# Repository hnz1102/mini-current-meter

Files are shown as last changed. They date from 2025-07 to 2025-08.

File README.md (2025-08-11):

<div align="center">
  <h1><code>Mini Current Meter</code></h1>
  <p>
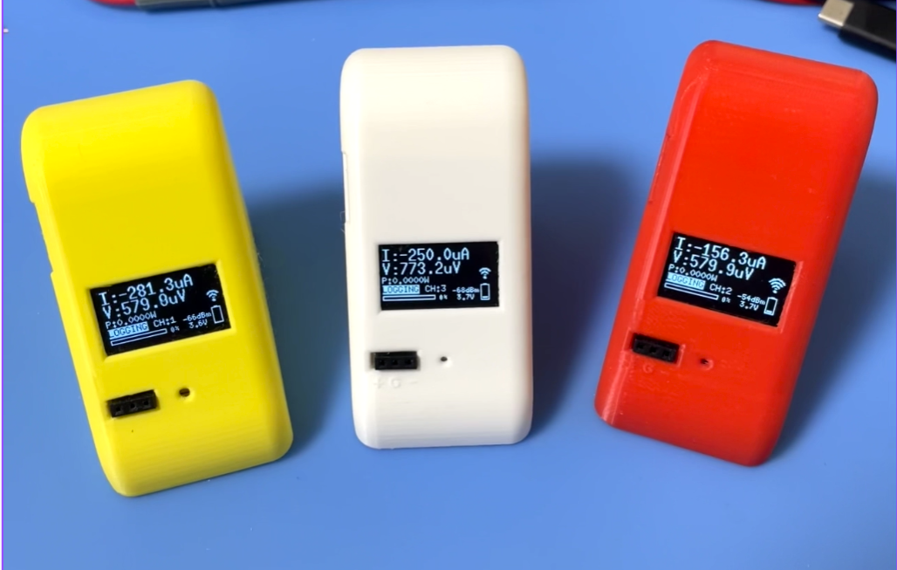
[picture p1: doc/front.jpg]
    
  </p>
</div>

# Mini Current Meter - Mini Size High-resolution Digital Power Monitor and Logger

This tool provides a logging function that captures data on voltage, current and power consumption. Voltage input range is from 0 to 35V, maximum current input is 10A. 

# Features

**High-resolution** - By using Texas Instruments INA228 IC - 20-bit delta-sigma ADC, it can obtain measurement data with 195µV bus voltage and 163.84mV shunt voltage resolution.

**Microcontroller on board** - No need for a client PC when measuring. Data is sent directly to the server.

**Transfer measurement data via WiFi** - This logger can transfer data to a Linux PC via WiFi network and you can view the dashboard graph in InfluxDB.

**Calibration Function** - Built-in calibration functionality with persistent storage. Long press the center button for 2+ seconds to perform automatic calibration that corrects voltage and current measurement offsets. Calibration results are automatically saved to non-volatile storage and restored on power-up.

**Change Channel** - This logger allows you to change the measurement channel by pushing the center button with a pin. Once you push the center button, the channel will change to the next channel. The channel cycles through 1, 2, 3, 4, and back to 1.

**Battery Powered** - Uses LiPo battery. It can run for 12 hours on a single charge. The battery is charged via USB Type-C port.

**Mini Size** - The dimensions are 37mm(W) x 67mm(D) x 55mm(H). It can be used in various locations.

# How to Use the Logger

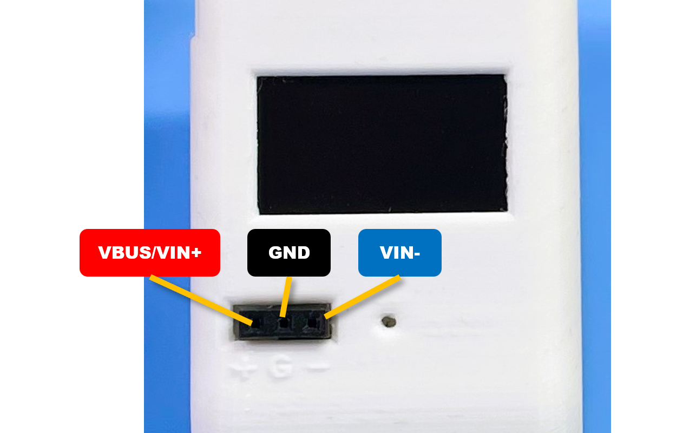
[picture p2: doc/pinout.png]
PinOut


This meter has a pin socket with three pins: VBUS/VIN+, GND, and VIN-. The VBUS/VIN+ pin is connected to the voltage input or the current input. The GND pin is connected to the ground of the voltage or current input. The VIN- pin is connected to the load side of the voltage or current input.

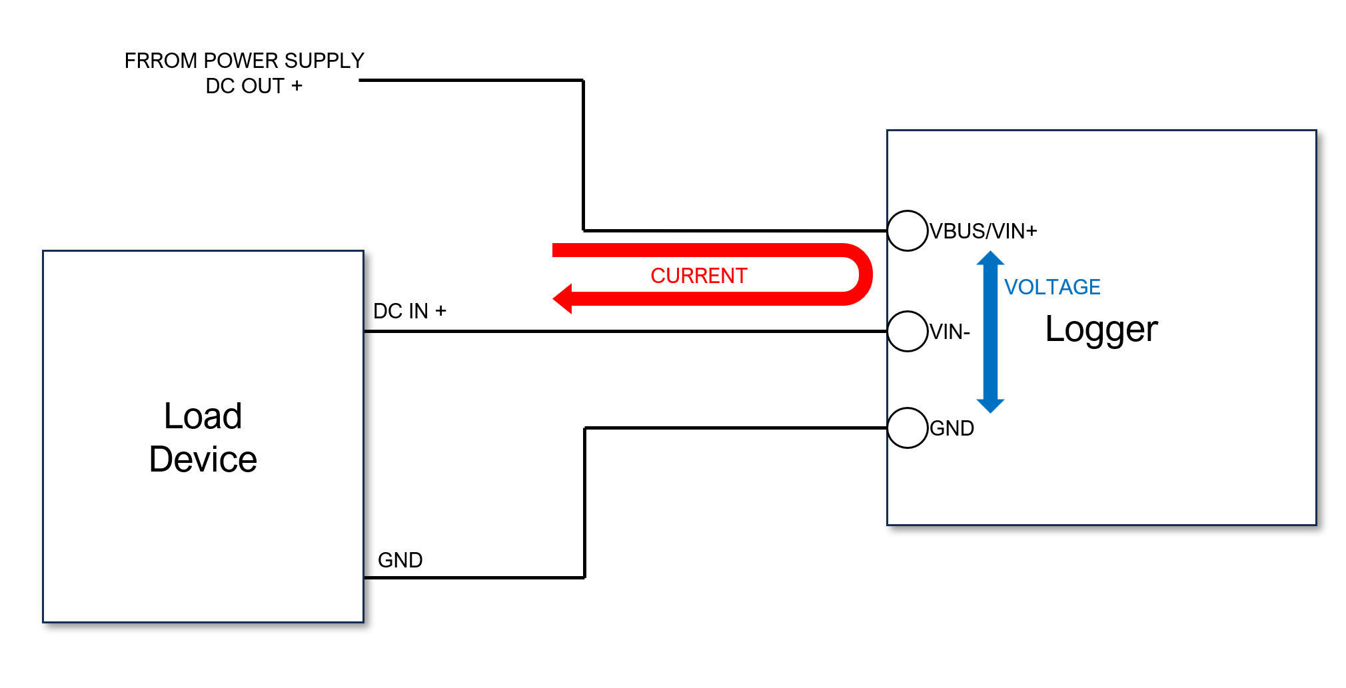
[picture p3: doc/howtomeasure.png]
How to connect


DO NOT CONNECT WITH REVERSE POLARITY BETWEEN VBUS/VIN+ AND GND. IF CONNECTED INCORRECTLY, THE ADC IC WILL BE DAMAGED.

The measurement interval time is fixed at 100ms. Each measurement data is sent to the server every 1 second.

The display shows the current voltage, current, power consumption, battery voltage, buffer consumption, WiFi connection status, and channel number.
If the WiFi Access Point cannot establish a connection, the display will not show the WiFi indicator. If voltage is measured while WiFi is not connected, the data is stored in the logger's internal memory buffer. The buffer that is not being sent to the server is indicated by a buffer bar on the display. When the buffer is full (the bar reaches the right edge of the display), measurement stops automatically. When WiFi is connected and data is transmitted to the server, the buffer bar shrinks to the left. When the buffer is full and measurement is stopped, measurement will resume automatically after the buffer drops below 50%.

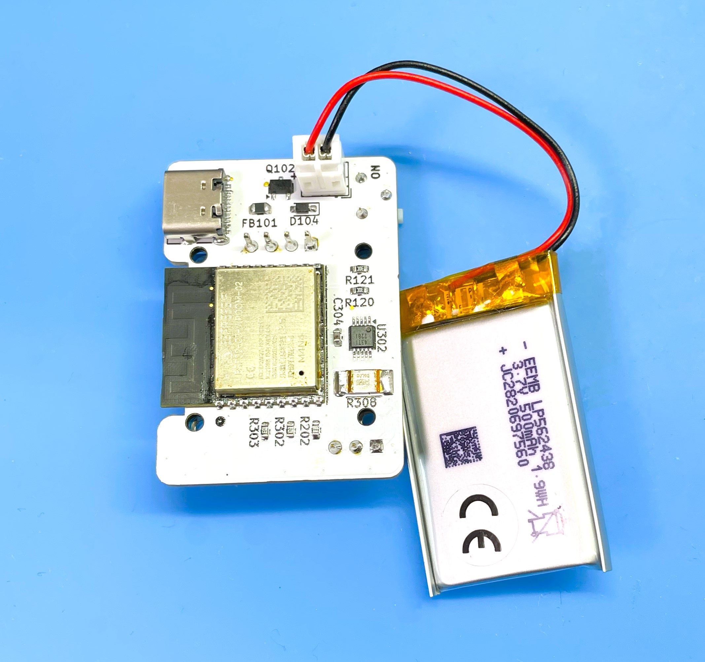
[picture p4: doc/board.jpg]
board


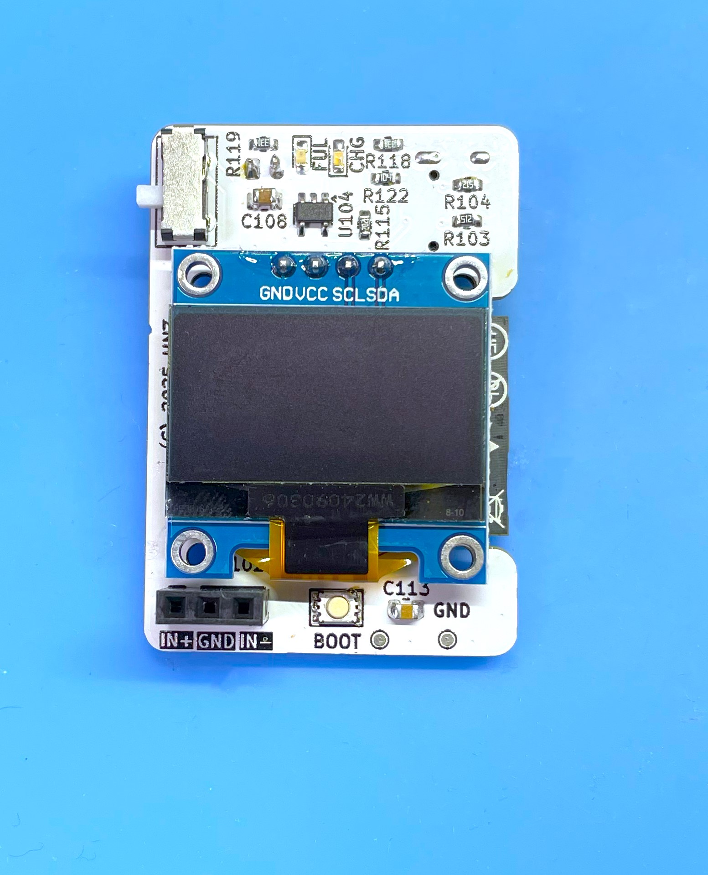
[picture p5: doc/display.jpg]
Display


If you send data to the server, you can see real-time data using the Dashboard in [InfluxDB](https://www.influxdata.com/influxdb/). If you have 3 meters, you can view data on the dashboard with different channels simultaneously.

These meters are small and light, so you can use them in various locations. For example, you can use them to measure circuit current on your breadboard, or you can measure the current at each measurement point on your breadboard circuit. 

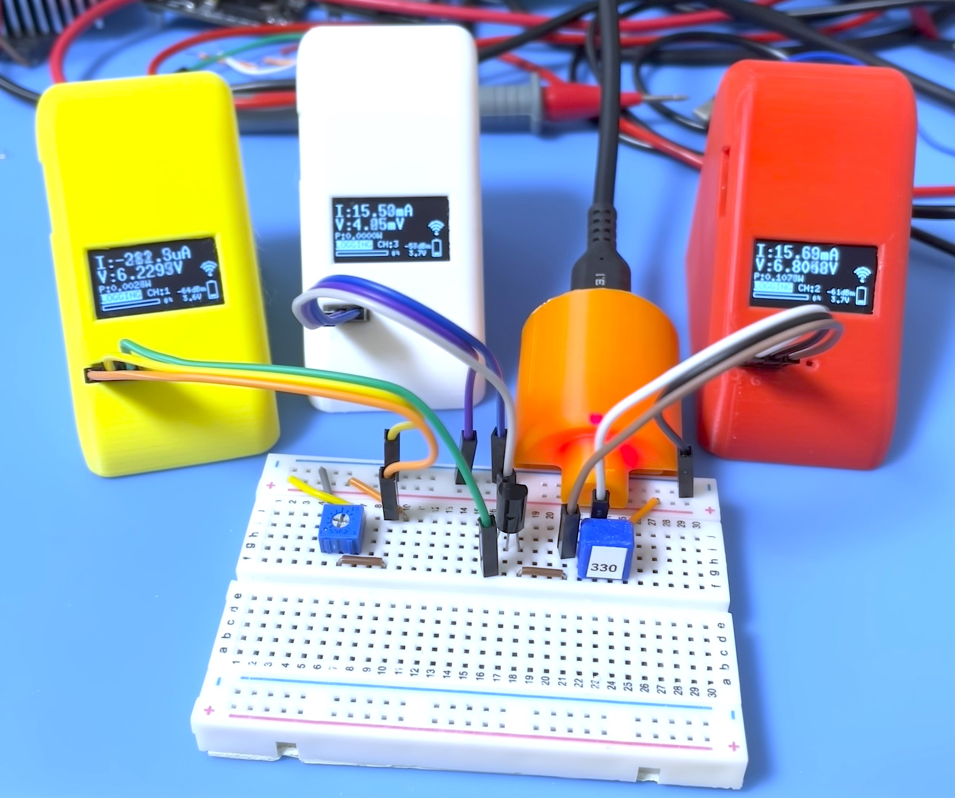
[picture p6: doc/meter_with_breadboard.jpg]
breadboard


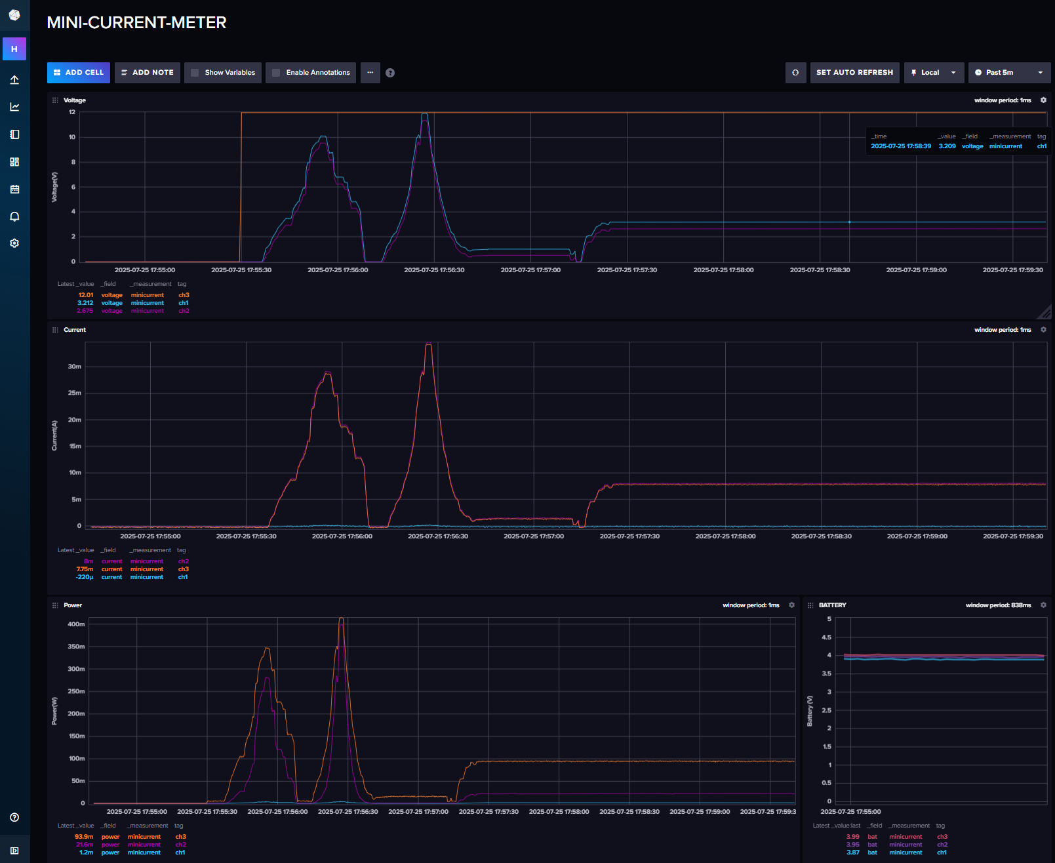
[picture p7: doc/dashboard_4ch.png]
dashboard


To charge the battery, simply connect to a USB Type-C port from a bus-powered USB port. During charging, the CHG LED is RED. After charging is complete, the FUL LED is GREEN and charging will stop automatically. However,

DO NOT CONTINUE CHARGING IF THE BATTERY IS FULL FOR A LONG TIME.

# Calibration Function

The Mini Current Meter includes built-in calibration functionality to correct measurement offsets and improve accuracy.

## How to Perform Calibration

1. **Prepare for calibration**: Ensure no current is flowing through the shunt resistor and no voltage is applied to the measurement inputs (VBUS/VIN+ and GND should be at the same potential).

2. **Start calibration**: Press and hold the center button for **2-5 seconds**. The display will show "Calibrating..." message.

3. **Calibration process**: The device automatically takes 300 samples over 3 seconds to calculate average voltage and current offsets.

4. **Completion**: When calibration is complete, the display will show "Calibration OK" for 2 seconds, and the offset values will be automatically saved to non-volatile storage.

## Button Functions

- **Short press** (< 2 seconds): Change measurement channel (1-4)
- **Long press** (2+ seconds): Perform calibration

## Calibration Features

- **Automatic offset correction**: Calibration corrects both voltage and current measurement offsets
- **Persistent storage**: Calibration results are automatically saved to NVS (Non-Volatile Storage) and restored on power-up
- **High accuracy**: Uses 300-sample averaging for precise offset calculation
- **User feedback**: Real-time status display during calibration process

## When to Calibrate

- **Initial setup**: Perform calibration when first using the device
- **Temperature changes**: Recalibrate if operating temperature changes significantly
- **Accuracy concerns**: If measurements appear to have a systematic offset
- **After firmware updates**: Recalibration recommended after major firmware changes

**Note**: Always ensure zero current flow and zero voltage difference during calibration for best results.

# Recent Updates

## Version 2025.08 - Calibration and Accuracy Improvements

- **Added calibration functionality**: Built-in calibration system with persistent storage
- **Improved measurement accuracy**: Automatic offset correction for voltage and current readings
- **Enhanced button handling**: Added debouncing and multi-function button support (channel change, calibration, reset)
- **NVS integration**: Calibration data automatically saved and restored across power cycles
- **User interface improvements**: Real-time calibration status display and user feedback
- **Error correction**: Fixed voltage measurement accuracy issues and ADC offset handling

# How to Build from Code and Install to the Unit

Using Ubuntu 22.04 LTS

1. Install Rust Compiler
```bash
sudo apt update && sudo apt -y install git python3 python3-pip gcc build-essential curl pkg-config libudev-dev libtinfo5 clang libclang-dev llvm-dev udev libssl-dev python3.10-venv
curl --proto '=https' --tlsv1.2 -sSf https://sh.rustup.rs | sh
```

select No.1

After installation, you need to set the environment variable for Rust.
Add the following line to your shell configuration file (e.g., `~/.bashrc`, `~/.zshrc`, etc.):
```bash
source "$HOME/.cargo/env"
```

2. Install toolchain for ESP32-C3
```bash
cargo install ldproxy
cargo install espup
cargo install cargo-espflash
```

At this time (2025-07-25), espup cannot be compiled. If you get an error, please use the following command to install the toolchain.
```bash
cargo install cargo-binstall
cargo binstall espup
```

```bash
espup install
espup update
```

Then, run the following command to set the environment for the ESP32-C3 toolchain:
```bash
. ./export-esp.sh
```

3. Add UDEV rules
```bash
sudo sh -c 'echo "SUBSYSTEMS==\"usb\", ATTRS{idVendor}==\"303a\", ATTRS{idProduct}==\"1001\", MODE=\"0666\"" > /etc/udev/rules.d/99-esp32.rules'
sudo udevadm control --reload-rules
sudo udevadm trigger
```

4. Download Mini Current Meter code
```bash
git clone https://github.com/hnz1102/mini-current-meter.git
cd mini-current-meter/code
``` 
5. Setting WiFi SSID, Password, and InfluxDB Server IP Address

You need to set the WiFi SSID, password, and InfluxDB server IP address in the configuration file.
You can find the configuration file 'cfg.toml.samp' in the `code` directory. You need to copy this file to `cfg.toml` and edit it.

```bash
nano code/cfg.toml

[mini-current-meter]
wifi_ssid = "XXXXXXXXXXXX"  # Set your WiFi SSID.
wifi_psk = "XXXXXXXXXXXXX"  # Set your WiFi Password.
shunt_resistance = "0.005"
influxdb_server = "<IP Address>:8086"  # Set your InfluxDB server IP address.
influxdb_api_key = "<API_KEY>" # Set your InfluxDB API Key.
influxdb_api = "/api/v2/write?org=<ORG>&bucket=LOGGER&precision=ns" # Set your InfluxDB API URL. You must set <ORG> same as Initial Organization Name.
influxdb_tag = "ch"
influxdb_measurement = "minicurrent"
max_records = "1023"
```

6. Connecting the Board and Setting Device and Toolchain
```bash
Connect the mini-current-meter via USB to this build code PC. Then, 
$ cargo espflash board-info
select /dev/ttyACM0
Chip type:         esp32c3 (revision v0.4)
Crystal frequency: 40MHz
Flash size:        4MB
Features:          WiFi, BLE
MAC address:       xx:xx:xx:xx:xx:xx

$ rustup component add rust-src --toolchain nightly-2023-06-10-x86_64-unknown-linux-gnu
```

7. Build Code and Write to Flash
```bash
$ cargo espflash flash --release --monitor
App/part. size:    964,240/3,145,728 bytes, 30.23%
[00:00:00] [========================================]      12/12      0x0                                                                       
[00:00:00] [========================================]       1/1       0x8000                                                                    
[00:00:11] [========================================]     546/546     0x10000                                                                   [2023-11-11T10:17:05Z INFO ] Flashing has completed!

Automatically boots!
```
# How to Install InfluxDB

1. Download [InfluxDB](https://docs.influxdata.com/influxdb/v2.7/install/?t=Linux) and Install
```bash
$ wget https://dl.influxdata.com/influxdb/releases/influxdb2-2.7.0-amd64.deb
$ sudo dpkg -i influxdb2-2.7.0-amd64.deb
$ sudo service influxdb start
```

2. Configure InfluxDB

```
Connect to 'http://<InfluxDB installed PC Address>:8086'
```
Click `GET STARTED` and set `Username`, `Password`, `Initial Organization Name`, and `Initial Bucket Name`
|Term|Value|
|---|---|
|Username|Set login username as InfluxDB administrator web console|
|Password|Set login password as InfluxDB administrator web console|
|Initial Organization Name| Organization Name ex. ORG|
|Initial Bucket Name| LOGGER |

After setting these, click `CONTINUE`.

3. Copy the Operator API Token

You can see the operator API token in the browser. YOU WON'T BE ABLE TO SEE IT AGAIN!
If you want to get a new API token, click `API Tokens` menu from `Sources` Icon, then click `GENERATE API TOKEN` and select `All access token`, click `Save`.
You can see the new API token and copy it.
After copying the token, click `CONFIGURE LATER`.

4. Import the Dashboard Template

Click the `Dashboard` icon, and select `Import Dashboard` from the `CREATE DASHBOARD` menu.

Drop the `mini-current-meter/dashboard/mini-current-meter.json` file to `Drop a file here`, then click `IMPORT JSON AS DASHBOARD`.

You can see the `Mini Current Meter Dashboard` panel on the Dashboards page.

Click this panel, and you can see the Mini Current Meter Dashboard.

If you want to customize the dashboard design, click the configure mark. You can change the graph design.

6. Start Mini Current Meter Logging and Send Data

Turn on the power switch. Logging data will be sent to InfluxDB. You can see the data on the dashboard.

## Schematic, PCB Gerber and Container 3D Data

There is schematic data in the hardware directory including 3D printing data as 3MF format files. 

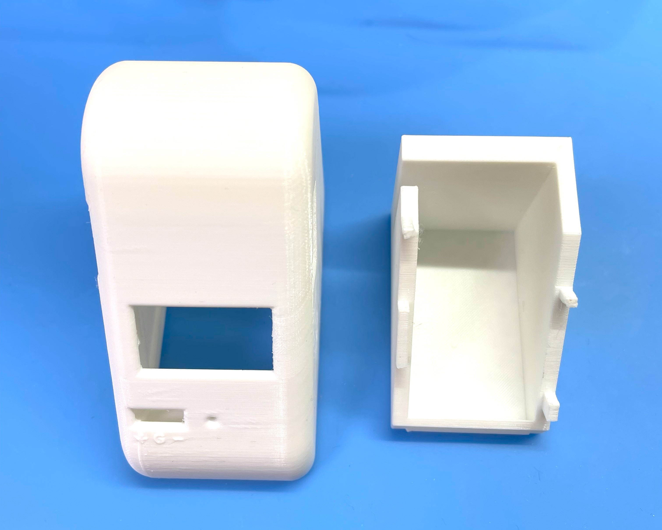
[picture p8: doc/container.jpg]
Container


## LICENSE
This source code is licensed under MIT. Other Hardware Schematic documents are licensed under CC-BY-SA V4.0.

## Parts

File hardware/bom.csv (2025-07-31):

Reference | Value | Footprint | Qty | digikey | DNP
C108 | 4.7uF | Capacitor_SMD:C_0805_2012Metric | 1 | 1276-1244-1-ND
C109,C113 | 1uF | Capacitor_SMD:C_0805_2012Metric | 2 | 1276-1029-1-ND
C111,C304 | 0.1uF | Capacitor_SMD:C_0603_1608Metric | 2 | 311-1088-1-ND
C112 | 10uF | Capacitor_SMD:C_0805_2012Metric | 1 | 587-1300-1-ND
D102 | LED RED | LED_SMD:LED_0603_1608Metric_Pad1.05x0.95mm_HandSolder | 1 | 3147-B1931URO-20D000114U1930CT-ND
D103 | LED GREEN | LED_SMD:LED_0603_1608Metric_Pad1.05x0.95mm_HandSolder | 1 | 3147-B1911PG--20D000514U1930CT-ND
D104 | CUS10F30 | Diode_SMD:D_SOD-323_HandSoldering | 1 | CUS10F30H3FCT-ND
FB101 | MH2029-601Y | Inductor_SMD:L_0805_2012Metric | 1 | MH2029-601YCT-ND
J101 | USB4105-GF-A | Lib:USB_C_5077CR-16-SMC2-BK-TR | 1 | 2073-USB4105-GF-ACT-ND
J102 | Conn_01x03 | Connector_PinSocket_2.54mm:PinSocket_1x03_P2.54mm_Vertical | 1 | https://akizukidenshi.com/catalog/g/g110098/
J103 | LiPo BATTERY | Connector_JST:JST_PH_B2B-PH-K_1x02_P2.00mm_Vertical | 1 | 455-1704-ND, Battey: https://www.amazon.com/EEMB-Battery-Rechargeable-Connector-Certified/dp/B09DPPMX14
Q102 | SSM3J332R | Package_TO_SOT_SMD:SOT-23 | 1 | 4518-SSM3J332RCT-ND
R103,R104 | 5.1K | Resistor_SMD:R_0603_1608Metric | 2 | 311-5.10KHRCT-ND
R106,R120,R121 | 20K 1% | Resistor_SMD:R_0603_1608Metric | 3 | 311-20.0KHRCT-ND
R107 | 12K 1% | Resistor_SMD:R_0603_1608Metric | 1 | 311-12.0KHRCT-ND
R108,R110,R202,R302,R303,R304 | 10K | Resistor_SMD:R_0603_1608Metric | 6 | 311-10KGRCT-ND
R115 | 2K | Resistor_SMD:R_0603_1608Metric | 1 | 311-2.0KGRCT-ND
R118,R119 | 330 | Resistor_SMD:R_0603_1608Metric | 2 | 311-330GRCT-ND
R122 | 100K | Resistor_SMD:R_0603_1608Metric | 1 | RMCF0603FT100KCT-ND
R308 | 5m | Resistor_SMD:R_2512_6332Metric_Pad1.40x3.35mm_HandSolder | 1 | 4506-PEWF2512D5L00Q9CT-ND
SW105 | SLIDE_SW | Lib:SLIDE_SW_IS1235-G | 1 | SLIDE_SW_IS1235-G https://akizukidenshi.com/catalog/g/g115368/
SW201 | 3.5x2.6 Tact SW | Lib:WS-TASV SMT Tact Switch | 1 | 732-435151014824CT-ND
TP101 | GND | TestPoint:TestPoint_Pad_D1.0mm | 1 | -
TP202 | BOOT | TestPoint:TestPoint_Pad_D1.0mm | 1 | -
U101 | ESP32-C3-WROOM-02-N4 | Lib:IC18_ESP32-C3-WROOM-02-N4_EXP | 1 | 1965-ESP32-C3-WROOM-02-N4CT-ND
U102 | SPX3819M5-L/TR | Package_TO_SOT_SMD:SOT-23-5 | 1 | 1016-1871-1-ND
U103 | SSD1306_DISPLAY | Lib:OLED I2C DISPLAY | 1 | https://akizukidenshi.com/catalog/g/g112031/
U104 | MCP73831-2-OT | Package_TO_SOT_SMD:SOT-23-5 | 1 | https://akizukidenshi.com/catalog/g/g113288/
U302 | INA228 | Package_SO:VSSOP-10_3x3mm_P0.5mm | 1 | 296-INA228AIDGSRCT-ND

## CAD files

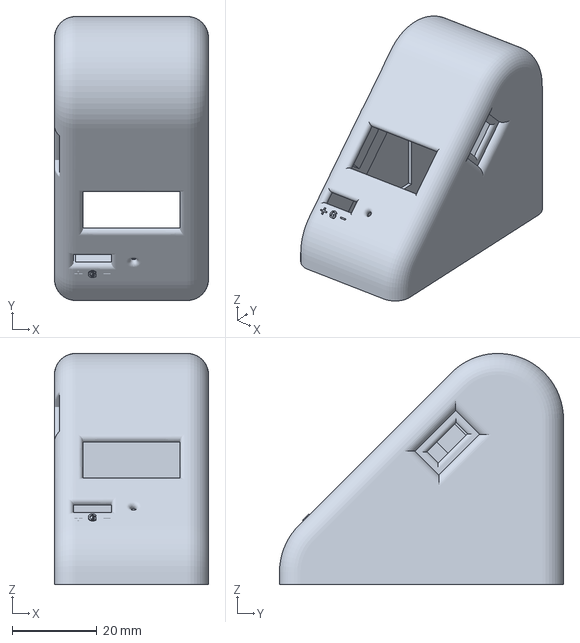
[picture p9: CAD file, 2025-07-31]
hardware/upper-v10.3mf
36.4 x 67.1 x 54.6 mm

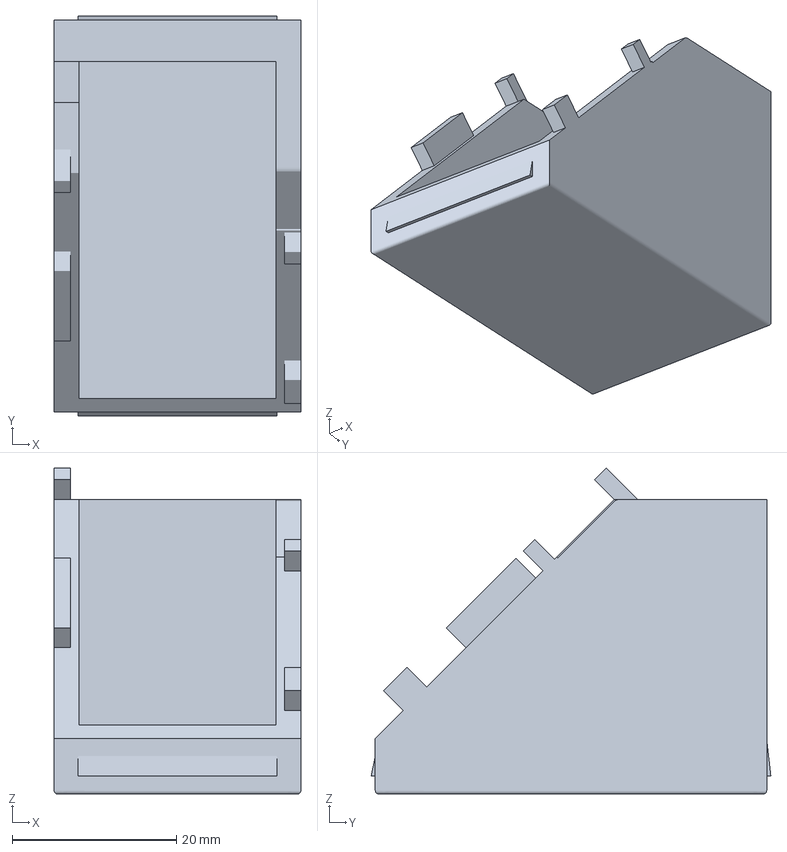
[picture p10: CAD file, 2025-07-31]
hardware/bottom-v10.3mf
30.0 x 48.6 x 39.6 mm

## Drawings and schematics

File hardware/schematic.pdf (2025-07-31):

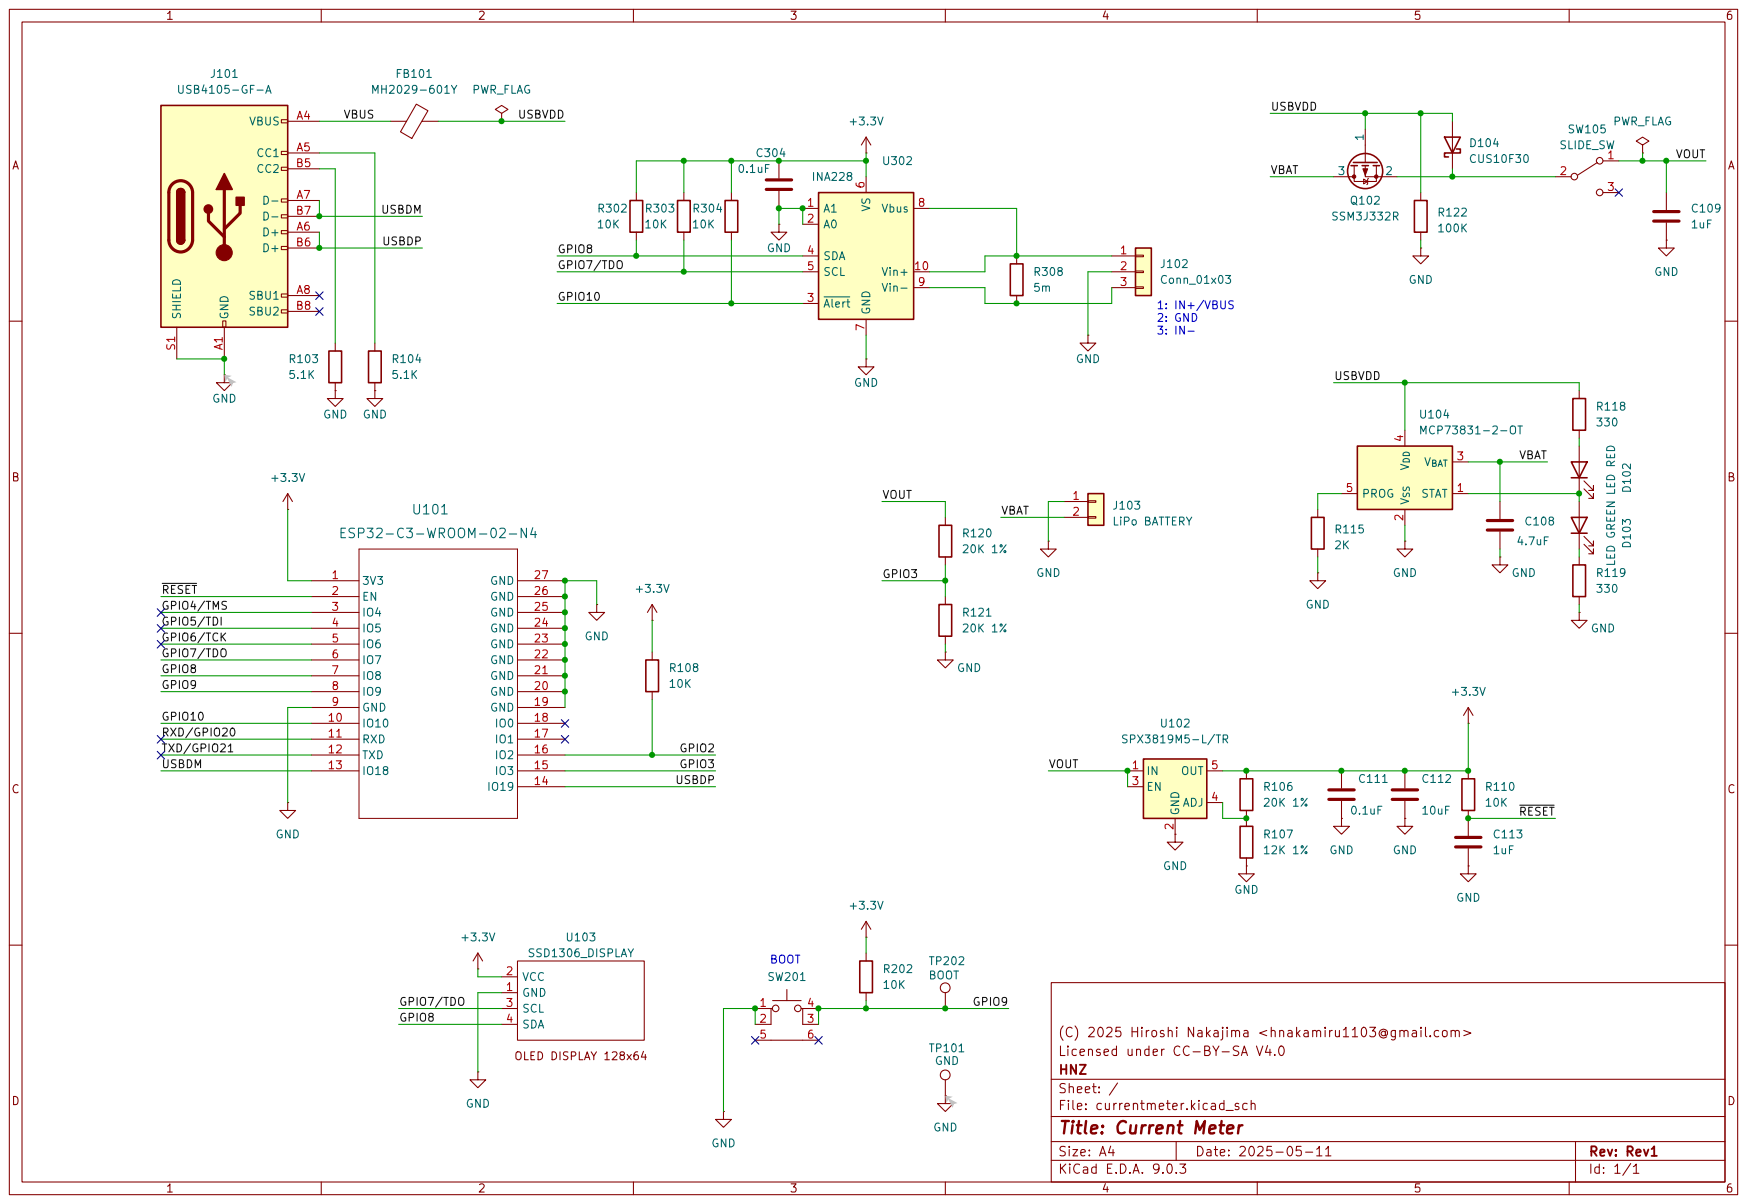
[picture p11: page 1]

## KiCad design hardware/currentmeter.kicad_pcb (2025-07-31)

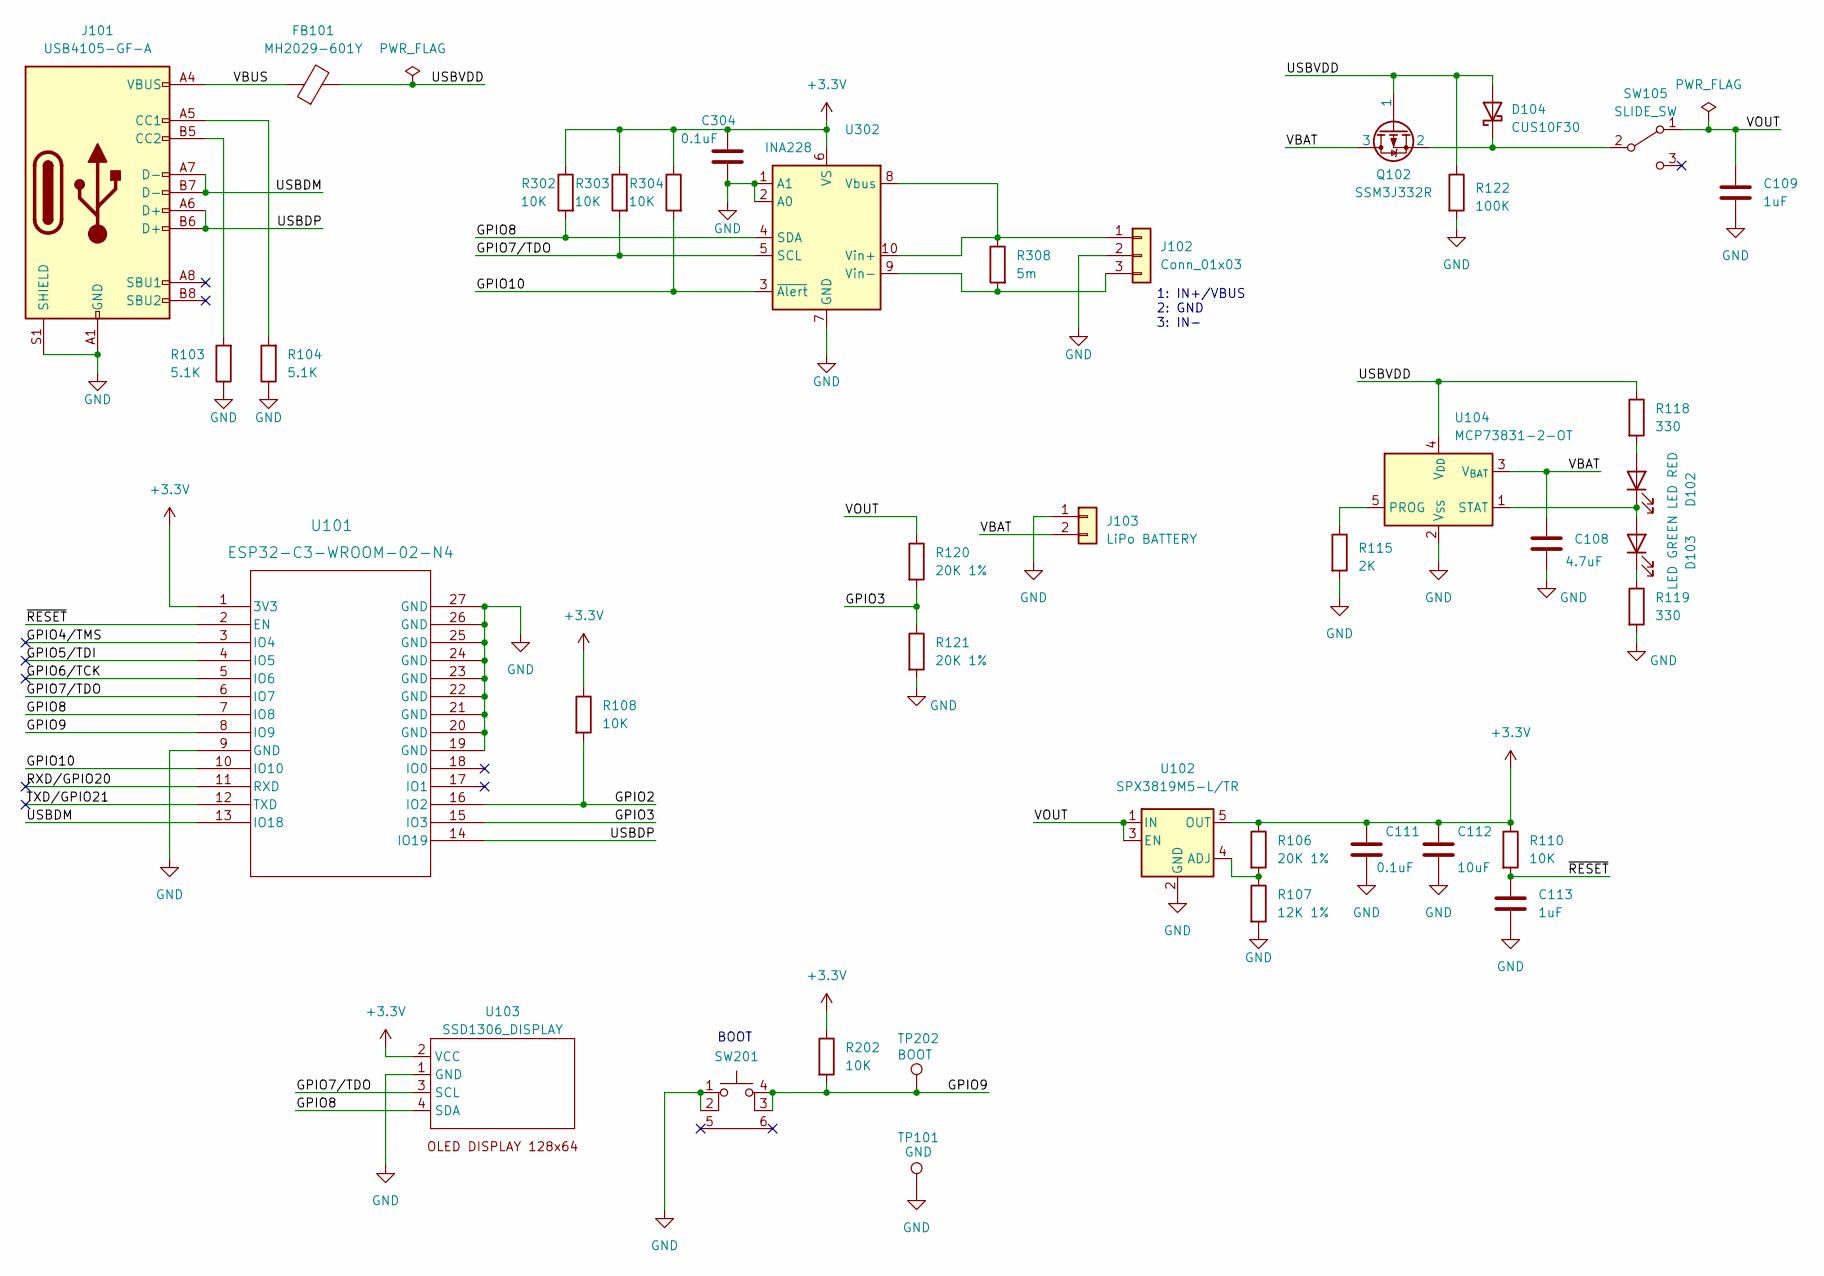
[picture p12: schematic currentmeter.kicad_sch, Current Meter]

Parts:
C108: 4.7uF; C_0805_2012Metric; digikey 1276-1244-1-ND
C109, C113: 1uF; C_0805_2012Metric; digikey 1276-1029-1-ND
C111, C304: 0.1uF; C_0603_1608Metric; digikey 311-1088-1-ND
C112: 10uF; C_0805_2012Metric; digikey 587-1300-1-ND
D102: LED RED; LED_0603_1608Metric_Pad1.05x0.95mm_HandSolder; digikey 3147-B1931URO-20D000114U1930CT-ND
D103: LED GREEN; LED_0603_1608Metric_Pad1.05x0.95mm_HandSolder; digikey 3147-B1911PG--20D000514U1930CT-ND
D104: CUS10F30; D_SOD-323_HandSoldering; digikey CUS10F30H3FCT-ND
FB101: MH2029-601Y; L_0805_2012Metric; digikey MH2029-601YCT-ND
J101: USB4105-GF-A; USB_C_5077CR-16-SMC2-BK-TR; digikey 2073-USB4105-GF-ACT-ND
J102: Conn_01x03; PinSocket_1x03_P2.54mm_Vertical
J103: LiPo BATTERY; JST_PH_B2B-PH-K_1x02_P2.00mm_Vertical; digikey 455-1704-ND, Battey: https://www.amazon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
Q102: SSM3J332R; SOT-23; digikey 4518-SSM3J332RCT-ND
R103, R104: 5.1K; R_0603_1608Metric; digikey 311-5.10KHRCT-ND
R106, R120, R121: 20K 1%; R_0603_1608Metric; digikey 311-20.0KHRCT-ND
R107: 12K 1%; R_0603_1608Metric; digikey 311-12.0KHRCT-ND
R108, R110, R202, R302, R303, R304: 10K; R_0603_1608Metric; digikey 311-10KGRCT-ND
R115: 2K; R_0603_1608Metric; digikey 311-2.0KGRCT-ND
R118, R119: 330; R_0603_1608Metric; digikey 311-330GRCT-ND
R122: 100K; R_0603_1608Metric; digikey RMCF0603FT100KCT-ND
R308: 5m; R_2512_6332Metric_Pad1.40x3.35mm_HandSolder; digikey 4506-PEWF2512D5L00Q9CT-ND
SW105: SLIDE_SW; SLIDE_SW_IS1235-G; digikey SLIDE_SW_IS1235-G https://akizukidenshi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
SW201: 3.5x2.6 Tact SW; WS-TASV SMT Tact Switch; digikey 732-435151014824CT-ND
TP101: GND; TestPoint_Pad_D1.0mm
TP202: BOOT; TestPoint_Pad_D1.0mm
U101: ESP32-C3-WROOM-02-N4; IC18_ESP32-C3-WROOM-02-N4_EXP; digikey 1965-ESP32-C3-WROOM-02-N4CT-ND
U102: SPX3819M5-L/TR; SOT-23-5; digikey 1016-1871-1-ND
U103: SSD1306_DISPLAY; OLED I2C DISPLAY
U104: MCP73831-2-OT; SOT-23-5
U302: INA228; VSSOP-10_3x3mm_P0.5mm; digikey 296-INA228AIDGSRCT-ND

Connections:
+3.3V: C111.1, C112.1, C304.1, R106.1, R108.1, R110.1, R202.1, R302.1, R303.1, R304.1, U101.1 (3V3), U102.5 (OUT), U103.2 (VCC), U302.6 (VS)
/GPIO2: R108.2, U101.16 (IO2)
/GPIO3: R120.2, R121.1, U101.15 (IO3)
/GPIO4/TMS: U101.3 (IO4)
/GPIO5/TDI: U101.4 (IO5)
/GPIO6/TCK: U101.5 (IO6)
/GPIO7/TDO: R303.2, U101.6 (IO7), U103.3 (SCL), U302.5 (SCL)
/GPIO8: R302.2, U101.7 (IO8), U103.4 (SDA), U302.4 (SDA)
/GPIO9: R202.2, SW201.3 (K), SW201.4 (A), TP202.1, U101.8 (IO9)
/GPIO10: R304.2, U101.10 (IO10), U302.3 (~Alert)
/RXD/GPIO20: U101.11 (RXD)
/TXD/GPIO21: U101.12 (TXD)
/USBDM: J101.A7 (D-), J101.B7 (D-), U101.13 (IO18)
/USBDP: J101.A6 (D+), J101.B6 (D+), U101.14 (IO19)
/USBVDD: D104.2 (A), FB101.2, Q102.1, R118.1, R122.1, U104.4 (V_{DD})
/VBAT: C108.1, J103.2, Q102.3, U104.3 (V_{BAT})
/VBUS: FB101.1, J101.A4 (VBUS), J101.A9 (VBUS), J101.B4 (VBUS), J101.B9 (VBUS)
/VOUT: C109.1, R120.1, SW105.1 (A), U102.1 (IN), U102.3 (EN)
/~RESET: C113.1, R110.2, U101.2 (EN)
GND: C108.2, C109.2, C111.2, C112.2, C113.2, C304.2, J101.A1 (GND), J101.A12 (GND), J101.B1 (GND), J101.B12 (GND), J101.S1 (SHIELD), J102.2, J103.1, R103.1, R104.1, R107.2, R115.2, R119.2, R121.2, R122.2, SW201.1, SW201.2, TP101.1, U101.9 (GND), U101.19 (GND), U101.20 (GND), U101.21 (GND), U101.22 (GND), U101.23 (GND), U101.24 (GND), U101.25 (GND), U101.26 (GND), U101.27 (GND), U102.2 (GND), U103.1 (GND), U104.2 (V_{SS}), U302.1 (A1), U302.2 (A0), U302.7 (GND)
unnamed: D102.2 (A), R118.2
unnamed: D102.1 (K), D103.2 (A), U104.1 (STAT)
unnamed: D103.1 (K), R119.1
unnamed: D104.1 (K), Q102.2, SW105.2 (B)
unnamed: J101.A5 (CC1), R104.2
unnamed: J101.B5 (CC2), R103.2
unnamed: J102.1, R308.1, U302.8 (Vbus), U302.10 (Vin+)
unnamed: J102.3, R308.2, U302.9 (Vin-)
unnamed: R106.2, R107.1, U102.4 (ADJ)
unnamed: R115.1, U104.5 (PROG)

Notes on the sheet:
BOOT
1: IN+/VBUS 2: GND 3: IN-

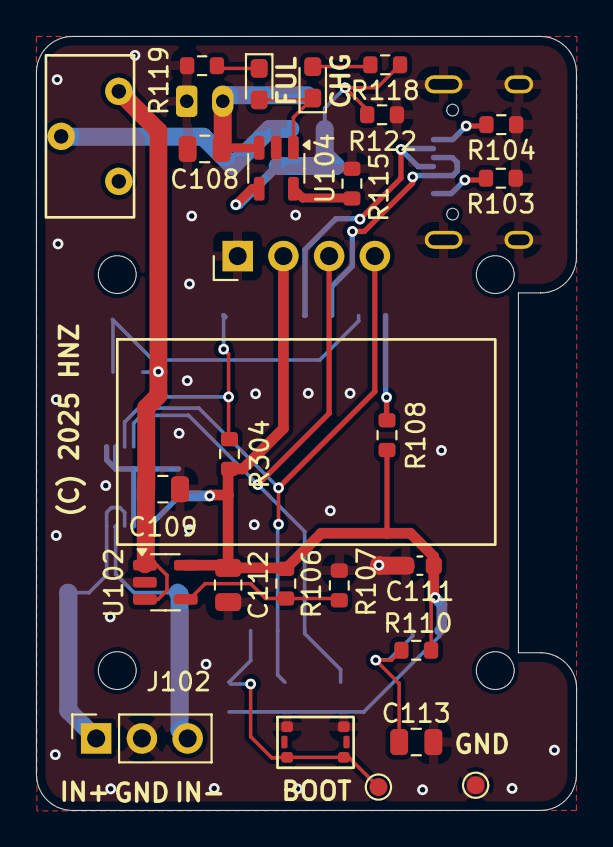
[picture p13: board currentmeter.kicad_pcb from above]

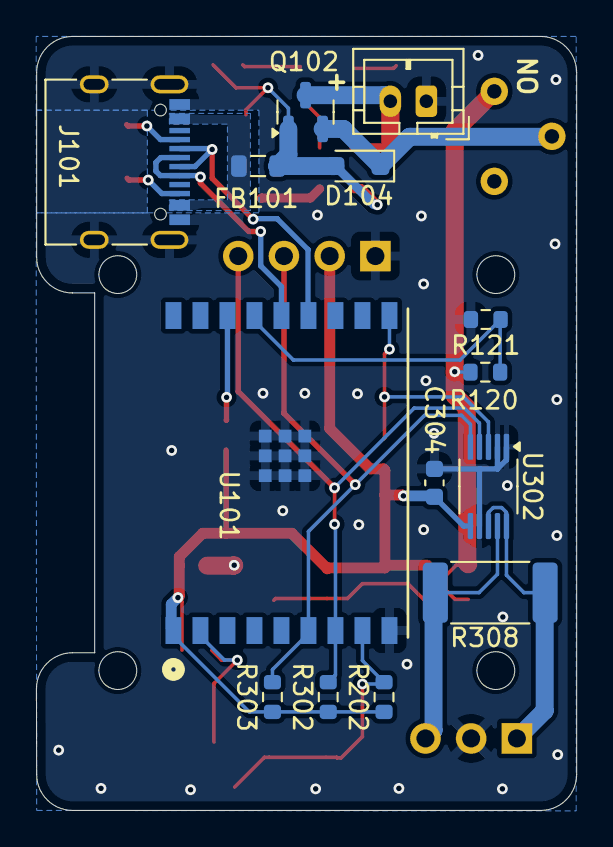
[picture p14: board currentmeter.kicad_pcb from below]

Board: 2 copper layers, 30.0 x 43.0 mm, 40 parts (14 on the bottom side), 25 nets.

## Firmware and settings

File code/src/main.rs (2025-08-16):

// This is mini-current-meter main program for ESP32-C3-WROOM.
// SPDX-License-Identifier: MIT
// Copyright (c) 2025 Hiroshi Nakajima

use std::{thread, time::Duration, sync::{Arc, Mutex}};
use esp_idf_hal::{prelude::*, i2c, gpio::*};
use esp_idf_hal::delay::BLOCK;
use esp_idf_hal::peripherals::Peripherals;
use log::*;
use std::time::SystemTime;
use esp_idf_hal::adc::oneshot::config::AdcChannelConfig;
use esp_idf_hal::adc::oneshot::config::Calibration;
use esp_idf_hal::adc::oneshot::*;
use esp_idf_hal::adc::attenuation::DB_11;
use esp_idf_hal::gpio::PinDriver;
use esp_idf_svc::sntp::{EspSntp, SyncStatus, SntpConf, OperatingMode, SyncMode};
use esp_idf_svc::wifi::EspWifi;
use esp_idf_svc::nvs::{EspNvs, EspNvsPartition, NvsDefault};
use chrono::{DateTime, Utc};

mod displayctl;
mod currentlogs;
mod wifi;
mod transfer;

use displayctl::{DisplayPanel, LoggingStatus, WifiStatus};
use currentlogs::{CurrentRecord, CurrentLog};
use transfer::Transfer;
use transfer::ServerInfo;

const ADCRANGE : bool = true; // true: 40.96mV, false: 163.84mV
const CALIBRATION_USE: bool = true;    // Enable or disable calibration
const WIFI_DELAY_START: u64 = 0;

#[toml_cfg::toml_config]
pub struct Config {
    #[default("")]
    wifi_ssid: &'static str,
    #[default("")]
    wifi_psk: &'static str,
    #[default("")]
    influxdb_server: &'static str,
    #[default("0.005")]
    shunt_resistance: &'static str,
    #[default("50")]
    shunt_temp_coefficient: &'static str,
    #[default("")]
    influxdb_api_key: &'static str,
    #[default("")]
    influxdb_api: &'static str,
    #[default("")]
    influxdb_measurement: &'static str,
    #[default("")]
    influxdb_tag: &'static str,
    #[default("1023")]
    max_records: &'static str,
}

fn main() -> anyhow::Result<()> {
    esp_idf_sys::link_patches();
    esp_idf_svc::log::EspLogger::initialize_default();

    // Initialize nvs
    unsafe {
        esp_idf_sys::nvs_flash_init();
    }
    
    // Parse configuration values
    let max_records = CONFIG.max_records.parse::<usize>().unwrap_or(1023);
    info!("Max records set to: {}", max_records);

    // Peripherals Initialize
    let peripherals = Peripherals::take().unwrap();
    
    // Shared I2C for both SSD1306 display and INA228 sensor
    let i2c = peripherals.i2c0;
    let scl = peripherals.pins.gpio7;
    let sda = peripherals.pins.gpio8;
    let config = i2c::I2cConfig::new().baudrate(100.kHz().into());
    let i2c_driver = i2c::I2cDriver::new(i2c, sda, scl, &config)?;
    
    // Clone the I2C driver for shared use (using Arc and Mutex for thread safety)
    use std::sync::{Arc, Mutex};
    let shared_i2c = Arc::new(Mutex::new(i2c_driver));
    
    // Create display with shared I2C
    let mut dp = DisplayPanel::new();
    let display_i2c = shared_i2c.clone();
    dp.start(display_i2c);

    // Initialize NVS
    let nvs_default_partition = EspNvsPartition::<NvsDefault>::take().unwrap();
    let mut nvs = match EspNvs::new(nvs_default_partition, "storage", true) {
        Ok(nvs) => { 
            info!("NVS storage area initialized"); 
            nvs 
        },
        Err(ref e) => {
            info!("NVS initialization failed {:?}", e);
            panic!("NVS initialization failed {:?}", e); 
        }
    };
    
    // Load current channel from NVS
    let mut channel: u8 = match nvs.get_u8("channel") {
        Ok(Some(ch)) => {
            info!("Loaded channel {} from NVS", ch);
            if ch >= 1 && ch <= 4 { ch } else { 1 } // Validate range
        },
        Ok(None) => {
            info!("No channel found in NVS, using default channel 1");
            1
        },
        Err(e) => {
            info!("Failed to read channel from NVS: {:?}, using default channel 1", e);
            1
        }
    };

    // Load configuration
    let server_info = ServerInfo::new(CONFIG.influxdb_server.to_string(), 
        CONFIG.influxdb_api_key.to_string(),
        CONFIG.influxdb_api.to_string(),
        CONFIG.influxdb_measurement.to_string(),
        CONFIG.influxdb_tag.to_string());

    // Use the shared I2C for INA sensor
    let sensor_i2c = shared_i2c.clone();

    // Initialize INA228 sensor
    match ADCRANGE {
        true => write_ina228_reg16(&sensor_i2c, 0x00, 0x0030)?, // Bit4: ADCRANGE=1(40.96mV), Bit5 Enables temperature compensation
        false => write_ina228_reg16(&sensor_i2c, 0x00, 0x0020)?, // Bit4: ADCRANGE=0(163.84mV), Bit5 Enables temperature compensation
    }
    let read_value = read_ina228_reg16(&sensor_i2c, 0x00)?;
    info!("INA228 Config Set to: {:04x}", read_value);

    // INA228 ADC Config
    let read_adc_config = read_ina228_reg16(&sensor_i2c, 0x01)?;
    info!("INA228 ADC Config Read: {:04x}", read_adc_config);
    // Mode: 0xF = Continuous bus voltage, shunt voltage and temperature
    // VBUSCT: 0x5 = 1052us Conversion Time for VBUS
    // VSHCT: 0x7 = 4120us Conversion Time for shunt voltage measurement
    // VTCT: 0x5 = 1052us Conversion Time for temperature measurement
    // AVG: 0x5 = 256 samples ADC sample averaging count, 0x6 = 512 samples, 0x7 = 1024 samples
    let write_adc_config : u16 = (0xF << 12) | (0x5 << 9) | (0x7 << 6) | (0x5 << 3) | 0x6; 
    write_ina228_reg16(&sensor_i2c, 0x01, write_adc_config)?;
    let read_adc_config = read_ina228_reg16(&sensor_i2c, 0x01)?;
    info!("INA228 ADC Config Set to: {:04x}", read_adc_config);

    // SHUNT_CAL
    let shunt_resistance = CONFIG.shunt_resistance.parse::<f32>().unwrap();
    let current_lsb = match ADCRANGE {
        true => {
            // 40.96mV range
            40.96 / 524_288.0
        },
        false => {
            // 163.84mV range
            163.84 / 524_288.0
        }
    };
    let shunt_cal_val = match ADCRANGE {
        true => 13107.2 * current_lsb * 1000_000.0 * shunt_resistance * 4.0, // 40.96mV range
        false => 13107.2 * current_lsb * 1000_000.0 * shunt_resistance, // 163.84mV range
    };
    let shunt_cal = shunt_cal_val as u16;
    info!("current_lsb={:?} shunt_cal_val={:?} shunt_cal={:?}", current_lsb, shunt_cal_val, shunt_cal);
    write_ina228_reg16(&sensor_i2c, 0x02, shunt_cal)?;
    let read_shunt_cal = read_ina228_reg16(&sensor_i2c, 0x02)?;
    info!("INA228 SHUNT_CAL Set to: {:04x}", read_shunt_cal);
    // Shunt Temperature Coefficient
    let shunt_temp_coefficient = CONFIG.shunt_temp_coefficient.parse::<u16>().unwrap();
    info!("Shunt Temperature Coefficient: {:?}", shunt_temp_coefficient);
    write_ina228_reg16(&sensor_i2c, 0x03, shunt_temp_coefficient)?;
    let read_shunt_temp_coefficient = read_ina228_reg16(&sensor_i2c, 0x03)?;
    info!("INA228 SHUNT_TEMP_COEFFICIENT Set to: {:04x}", read_shunt_temp_coefficient);

    // Temperature Measurement
    let temperature: f32 = read_ina228_reg16(&sensor_i2c, 0x06)? as f32 * 7.8125;
    info!("Initial Temperature Read: {:.2}°C", temperature / 1000.0);
    
    // Load calibration offsets from NVS
    let mut average_current_offset: f32 = {
        let mut buffer = [0u8; 4];
        match nvs.get_blob("current_offset", &mut buffer) {
            Ok(Some(data)) if data.len() == 4 => {
                let offset_bytes: [u8; 4] = [data[0], data[1], data[2], data[3]];
                let offset = f32::from_le_bytes(offset_bytes);
                info!("Loaded current offset from NVS: {:.6}A", offset);
                offset
            },
            Ok(Some(data)) => {
                info!("Invalid current offset size in NVS (got {} bytes), using default 0.0A", data.len());
                0.0
            },
            Ok(None) => {
                info!("No current offset found in NVS, using default 0.0A");
                0.0
            },
            Err(e) => {
                info!("Failed to read current offset from NVS: {:?}, using default 0.0A", e);
                0.0
            }
        }
    };
    
    let mut average_voltage_offset: f32 = {
        let mut buffer = [0u8; 4];
        match nvs.get_blob("voltage_offset", &mut buffer) {
            Ok(Some(data)) if data.len() == 4 => {
                let offset_bytes: [u8; 4] = [data[0], data[1], data[2], data[3]];
                let offset = f32::from_le_bytes(offset_bytes);
                info!("Loaded voltage offset from NVS: {:.6}V", offset);
                offset
            },
            Ok(Some(data)) => {
                info!("Invalid voltage offset size in NVS (got {} bytes), using default 0.0V", data.len());
                0.0
            },
            Ok(None) => {
                info!("No voltage offset found in NVS, using default 0.0V");
                0.0
            },
            Err(e) => {
                info!("Failed to read voltage offset from NVS: {:?}, using default 0.0V", e);
                0.0
            }
        }
    };
    
    // Display loaded calibration info
    if (average_current_offset != 0.0 || average_voltage_offset != 0.0) && CALIBRATION_USE {
        info!("Using stored calibration - Current offset: {:.6}A, Voltage offset: {:.6}V", 
              average_current_offset, average_voltage_offset);
    } else {
        info!("No calibration data found - using zero offsets");
        average_current_offset = 0.0;
        average_voltage_offset = 0.0;
    }

    // GPIO9 Button for channel selection (polling method)
    let channel_select_pin = peripherals.pins.gpio9;
    let mut channel_select_button = PinDriver::input(channel_select_pin)?;
    channel_select_button.set_pull(Pull::Up)?;

    // Temperature Logs
    let mut clogs = CurrentRecord::new();

    // WiFi
    let mut wifi_enable : bool = false;
    let mut wifi_device: Option<Box<EspWifi>>;
    match wifi::wifi_connect(peripherals.modem, CONFIG.wifi_ssid, CONFIG.wifi_psk) {
        Ok(wifi) => { 
            wifi_device = Some(wifi);
        },
        Err(ref e) => { 
            info!("{:?}", e); 
            wifi_device = None;
        }
    }

    // NTP Server
    let sntp_conf = SntpConf {
        servers: ["time.aws.com",
                    "time.google.com",
                    "time.cloudflare.com",
                    "ntp.nict.jp"],
        operating_mode: OperatingMode::Poll,
        sync_mode: SyncMode::Immediate,
    };
    let ntp = EspSntp::new(&sntp_conf).unwrap();

    // NTP Sync
    info!("NTP Sync Start..");

    // wait for sync
    let mut sync_count = 0;
    while ntp.get_sync_status() != SyncStatus::Completed {
        sync_count += 1;
        if sync_count > 1000 {
            info!("NTP Sync Timeout");
            break;
        }
        thread::sleep(Duration::from_millis(10));
    }
    let now = SystemTime::now();
    let dt_now : DateTime<Utc> = now.into();
    let formatted = format!("{}", dt_now.format("%Y-%m-%d %H:%M:%S"));
    info!("NTP Sync Completed: {}", formatted);

    let mut txd =  Transfer::new(server_info);
    txd.start()?;
    
    // Initialize with loaded channel tag
    let mut tag = format!("ch{}", channel);
    txd.set_tag(tag.clone());
    info!("Using channel {} (tag: {})", channel, tag);
    
    // Set initial channel on display
    dp.set_channel(channel as u32);
    
    // ADC GPIO0
    let mut adc = AdcDriver::new(peripherals.adc1)?;
    let mut adc_config = AdcChannelConfig {
        attenuation: DB_11,
        calibration: Calibration::Curve, // Use curve calibration for better accuracy
        ..Default::default()
    };
    let mut adc_pin = AdcChannelDriver::new(&mut adc, peripherals.pins.gpio3, &mut adc_config)?;

    // loop
    let mut logging_start = true;
    let mut logging_stopped_by_buffer_full = false;  // Track if logging was stopped due to buffer full
    let mut rssi : i32;
    if WIFI_DELAY_START > 0 {
        wifi_device.as_mut().map(|wifi| {
            wifi::stop_wifi(wifi).unwrap();
        });
    }
    let start_time = SystemTime::now();
    loop {
        thread::sleep(Duration::from_millis(100));

        if SystemTime::now().duration_since(start_time).unwrap().as_secs() < WIFI_DELAY_START {
            wifi_enable = true;
        }
        else {
            if wifi_enable == false {
                if let Some(ref mut wifi) = wifi_device {
                    wifi_reconnect(wifi, &mut dp);
                }
            }
            // Get RSSI
            rssi = wifi::get_rssi();
            dp.set_wifi_rssi(rssi);
            if rssi == 0 {
                if let Some(ref mut wifi) = wifi_device {
                    if wifi_reconnect(wifi, &mut dp) {
                        wifi_enable = true;
                    } else {
                        wifi_enable = false;
                    }
                } else {
                    dp.set_wifi_status(WifiStatus::Disconnected);
                    wifi_enable = false;
                }
            }
            else {
                dp.set_wifi_status(WifiStatus::Connected);
                wifi_enable = true;
            }
        }

        // Button polling with debounce and long press detection
        static mut LAST_BUTTON_STATE: bool = true;
        static mut BUTTON_PRESS_START_TIME: u64 = 0;
        static mut CALIBRATION_IN_PROGRESS: bool = false;
        static mut MESSAGE_CLEAR_TIME: u64 = 0;
        static mut LONG_PRESS_TRIGGERED: bool = false;  // Track if long press was already triggered
        
        const LONG_PRESS_TIME_MS: u64 = 2000;  // 2 seconds for calibration
        
        let current_button_state = channel_select_button.is_high();
        let current_time = SystemTime::now().duration_since(SystemTime::UNIX_EPOCH).unwrap().as_millis() as u64;
        
        unsafe {
            // Clear message after timeout
            if MESSAGE_CLEAR_TIME > 0 && current_time >= MESSAGE_CLEAR_TIME {
                dp.set_err_message("".to_string());
                MESSAGE_CLEAR_TIME = 0;
            }
            
            if LAST_BUTTON_STATE && !current_button_state {
                BUTTON_PRESS_START_TIME = current_time;
                LONG_PRESS_TRIGGERED = false;  // Reset the trigger flag
                info!("Button press detected");
            }
            
            // Check for long press (2+ seconds) for calibration
            if !current_button_state && 
                (current_time - BUTTON_PRESS_START_TIME) >= LONG_PRESS_TIME_MS && 
                !CALIBRATION_IN_PROGRESS &&
                !LONG_PRESS_TRIGGERED {
                
                CALIBRATION_IN_PROGRESS = true;
                LONG_PRESS_TRIGGERED = true;
                info!("Long press detected - starting calibration...");
                dp.set_err_message("Calibrating...".to_string());
            
                // Perform calibration
                match calibration(&sensor_i2c, current_lsb) {
                    Ok((current_offset, voltage_offset)) => {
                        average_current_offset = current_offset;
                        average_voltage_offset = voltage_offset;
                        info!("Calibration completed - Current offset: {:.6}A, Voltage offset: {:.6}V", 
                                current_offset, voltage_offset);
                        
                        // Save calibration offsets to NVS
                        let current_offset_bytes = current_offset.to_le_bytes();
                        let voltage_offset_bytes = voltage_offset.to_le_bytes();
                        
                        match nvs.set_blob("current_offset", &current_offset_bytes) {
                            Ok(_) => {
                                info!("Current offset saved to NVS: {:.6}A", current_offset);
                            },
                            Err(e) => {
                                info!("Failed to save current offset to NVS: {:?}", e);
                            }
                        }
                        
                        match nvs.set_blob("voltage_offset", &voltage_offset_bytes) {
                            Ok(_) => {
                                info!("Voltage offset saved to NVS: {:.6}V", voltage_offset);
                            },
                            Err(e) => {
                                info!("Failed to save voltage offset to NVS: {:?}", e);
                            }
                        }
                        
                        dp.set_err_message("Calibration OK".to_string());
                        MESSAGE_CLEAR_TIME = current_time + 2000; // Clear after 2 seconds
                    },
                    Err(e) => {
                        info!("Calibration failed: {:?}", e);
                        dp.set_err_message("Calibration Failed".to_string());
                        MESSAGE_CLEAR_TIME = current_time + 2000; // Clear after 2 seconds
                    }
                }
            }
            
            // Button release detected (low to high transition after debounce)
            if !LAST_BUTTON_STATE && current_button_state {
                let press_duration = current_time - BUTTON_PRESS_START_TIME;
                
                if !CALIBRATION_IN_PROGRESS && press_duration < LONG_PRESS_TIME_MS {
                    // Short press - change channel
                    channel += 1;
                    if channel > 4 {
                        channel = 1;
                    }
                    tag = format!("ch{}", channel);
                    info!("Channel changed to {}", tag);
                    dp.set_channel(channel as u32);
                    txd.set_tag(tag.clone());
                    
                    // Save current channel to NVS
                    match nvs.set_u8("channel", channel) {
                        Ok(_) => {
                            info!("Channel {} saved to NVS", channel);
                        },
                        Err(e) => {
                            info!("Failed to save channel to NVS: {:?}", e);
                        }
                    }
                }
                
                CALIBRATION_IN_PROGRESS = false;
                LONG_PRESS_TRIGGERED = false;  // Reset the trigger flag on button release
                info!("Button released after {}ms", press_duration);
            }
            
            LAST_BUTTON_STATE = current_button_state;
        }

        if wifi_enable == false{
            dp.set_wifi_status(WifiStatus::Disconnected);
        }
        else {
            dp.set_wifi_status(WifiStatus::Connected);
        }

        if logging_start == true {
            //startstop_led.set_high()?;
            dp.set_current_status(LoggingStatus::Start);
        }
        else {
            //startstop_led.set_low()?;
            dp.set_current_status(LoggingStatus::Stop);
        }

       // Read Current/Voltage
        let mut data = CurrentLog::default();
        // Timestamp
        let now = SystemTime::now();
        // set clock in ns
        data.clock = now.duration_since(SystemTime::UNIX_EPOCH).unwrap().as_nanos();

        // Voltage
        match voltage_read(&sensor_i2c) {
            Ok(vbus) => {
                data.voltage = vbus - average_voltage_offset;
                // info!("vbus={:?} {:?}V", vbus_buf, data.voltage);
            },
            Err(e) => {
                info!("{:?}", e);
//                dp.set_message(format!("{:?}", e), true, 1000);
            }
        }
        // Current
        match current_read(&sensor_i2c, current_lsb) {
            Ok(current) => {
                data.current = current - average_current_offset;
            },
            Err(e) => {
                info!("{:?}", e);
                // dp.set_message(format!("{:?}", e), true, 1000);
            }
        }
        // let shunt_voltage_measured = match ADCRANGE {
        //     true => (read_ina228_reg24(&sensor_i2c, 0x04)? >> 4) as f32 * 78.125,
        //     false => (read_ina228_reg24(&sensor_i2c, 0x04)? >> 4) as f32 * 312.5,
        // };
        // info!("Shunt Voltage Measured: {:.2}nV", shunt_voltage_measured);
        // Power
        match power_read(&sensor_i2c, current_lsb) {
            Ok(power) => {
                data.power = power;
            },
            Err(e) => {
                info!("{:?}", e);
                // dp.set_message(format!("{:?}", e), true, 1000);
            }
        }

        // battery voltage 
        data.battery =  adc_pin.read().unwrap() as f32 * 2.0 / 1000.0;
        // info!("voltage={:.2}V current={:.5}A power={:.5}W battery={:.2}V",
        //     data.voltage, data.current, data.power, data.battery);
        dp.set_battery(data.battery);
        dp.set_voltage(data.voltage, data.current, data.power);
        if logging_start {
            clogs.record(data);
        }
        let current_record = clogs.get_size();
        if current_record >= max_records {
            logging_start = false;  // Auto stop logging if buffer is full.
            logging_stopped_by_buffer_full = true;  // Mark that logging was stopped due to buffer full
        }
        
        // Restart logging if it was stopped due to buffer full and buffer usage drops below 50%
        if logging_stopped_by_buffer_full && !logging_start && current_record < max_records / 2 {
            logging_start = true;
            logging_stopped_by_buffer_full = false;
            info!("Logging restarted: buffer usage dropped below 50% ({}/{})", current_record, max_records);
        }
        
        dp.set_buffer_watermark((current_record as u32) * 100 / max_records as u32);

        if wifi_enable == true && current_record > 0 {
            let logs = clogs.get_all_data();
            let txcount = txd.set_transfer_data(logs);
            if txcount > 0 {
                clogs.remove_data(txcount);
            }
        }
    }
}
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

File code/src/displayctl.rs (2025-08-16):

use log::*;
use std::{thread, time::Duration, sync::Arc, sync::Mutex};
use esp_idf_hal::i2c;
use ssd1306::{I2CDisplayInterface, prelude::*, Ssd1306};
use embedded_graphics::{
    mono_font::{ascii::{FONT_10X20, FONT_5X8, FONT_6X10}, MonoTextStyle, MonoTextStyleBuilder},
    pixelcolor::BinaryColor,
    text::{Text},
    geometry::{Point, Size},
    prelude::*,
    image::Image,
    primitives::{Rectangle, PrimitiveStyle},
};
use tinybmp::Bmp;

pub enum LoggingStatus {
    Start,
    Stop,
}

pub enum WifiStatus {
    Disconnected,
    Connecting,
    Connected,
}

struct DisplayText {
    voltage: f32,
    current: f32,
    power: f32,
    wifi_rssi: i32,
    message: String,
    battery: f32,
    status: LoggingStatus,
    wifi: WifiStatus,
    buffer_water_mark: u32,
    channel: u32,
    voltage_range: u8,  // 0=mV, 1=V
    current_range: u8,  // 0=mA, 1=A
    power_range: u8,    // 0=mW, 1=W
}

pub struct DisplayPanel {
    txt: Arc<Mutex<DisplayText>>
}

impl DisplayPanel {

    pub fn new() -> DisplayPanel {
        DisplayPanel { txt: Arc::new(Mutex::new(
            DisplayText {voltage: 0.0,
                         message: "".to_string(),
                         current: 0.0,
                         power: 0.0,
                         wifi_rssi: 0,
                         battery: 0.0,
                         status: LoggingStatus::Stop,
                         wifi: WifiStatus::Disconnected,
                         buffer_water_mark: 0,
                         channel: 1, // Default channel
                         voltage_range: 1, // Default to V
                         current_range: 1, // Default to A
                         power_range: 1,   // Default to W
                     })) }
    }

    pub fn start(&mut self, shared_i2c: Arc<Mutex<i2c::I2cDriver<'static>>>)
    {
        let txt = self.txt.clone();
        let _th = thread::spawn(move || {
            info!("Start Display Thread.");
            
            // Create a simple wrapper that implements the required traits for SSD1306
            struct I2CWrapper {
                driver: Arc<Mutex<i2c::I2cDriver<'static>>>,
            }
            
            impl embedded_hal_0_2::blocking::i2c::Write for I2CWrapper {
                type Error = ();
                
                fn write(&mut self, address: u8, bytes: &[u8]) -> Result<(), Self::Error> {
                    let mut driver = self.driver.lock().unwrap();
                    driver.write(address, bytes, esp_idf_hal::delay::BLOCK).map_err(|_| ())
                }
            }
            
            let wrapper = I2CWrapper { driver: shared_i2c };
            let interface = I2CDisplayInterface::new(wrapper);
            let mut display = Ssd1306::new(interface, 
                DisplaySize128x64,
                ssd1306::prelude::DisplayRotation::Rotate0)
                .into_buffered_graphics_mode();
                
            if let Err(e) = display.init() {
                info!("Display init failed: {:?}", e);
                return;
            }
            
            let style_large = MonoTextStyle::new(&FONT_10X20, BinaryColor::On);
            // let style_large_inv = MonoTextStyleBuilder::new()
            //     .font(&FONT_10X20)
            //     .text_color(BinaryColor::Off)
            //     .background_color(BinaryColor::On)
            //     .build();
            let style_small = MonoTextStyle::new(&FONT_5X8, BinaryColor::On);
            let style_middle = MonoTextStyle::new(&FONT_6X10, BinaryColor::On);
            let style_middle_inv = MonoTextStyleBuilder::new()
                .font(&FONT_6X10)
                .text_color(BinaryColor::Off)
                .background_color(BinaryColor::On)
                .build();
            
            // Wifi BMP
            let wifibmp0 = Bmp::from_slice(include_bytes!("./img/wifi-0.bmp")).unwrap();
            let wifi_img0: Image<Bmp<BinaryColor>> = Image::new(&wifibmp0, Point::new(108,20));
            let wifibmp1 = Bmp::from_slice(include_bytes!("./img/wifi-1.bmp")).unwrap();
            let wifi_img1: Image<Bmp<BinaryColor>> = Image::new(&wifibmp1, Point::new(108,20));
            let wifibmp2 = Bmp::from_slice(include_bytes!("./img/wifi-2.bmp")).unwrap();
            let wifi_img2: Image<Bmp<BinaryColor>> = Image::new(&wifibmp2, Point::new(108,20));
            let wifibmp3 = Bmp::from_slice(include_bytes!("./img/wifi-3.bmp")).unwrap();
            let wifi_img3: Image<Bmp<BinaryColor>> = Image::new(&wifibmp3, Point::new(108,20));
            let wifibmp4 = Bmp::from_slice(include_bytes!("./img/wifi-4.bmp")).unwrap();
            let wifi_img4: Image<Bmp<BinaryColor>> = Image::new(&wifibmp4, Point::new(108,20));

            // Battery BMP
            let bat_x = 112;
            let bat_y = 42;
            let bat0 = Bmp::from_slice(include_bytes!("./img/battery-0.bmp")).unwrap();
            let bat0_img: Image<Bmp<BinaryColor>> = Image::new(&bat0, Point::new(bat_x, bat_y));
            let bat20 = Bmp::from_slice(include_bytes!("./img/battery-20.bmp")).unwrap();
            let bat20_img: Image<Bmp<BinaryColor>> = Image::new(&bat20, Point::new(bat_x, bat_y));
            let bat40 = Bmp::from_slice(include_bytes!("./img/battery-40.bmp")).unwrap();
            let bat40_img: Image<Bmp<BinaryColor>> = Image::new(&bat40, Point::new(bat_x, bat_y));
            let bat60 = Bmp::from_slice(include_bytes!("./img/battery-60.bmp")).unwrap();
            let bat60_img: Image<Bmp<BinaryColor>> = Image::new(&bat60, Point::new(bat_x, bat_y));
            let bat80 = Bmp::from_slice(include_bytes!("./img/battery-80.bmp")).unwrap();
            let bat80_img: Image<Bmp<BinaryColor>> = Image::new(&bat80, Point::new(bat_x, bat_y));
            let bat100 = Bmp::from_slice(include_bytes!("./img/battery-100.bmp")).unwrap();
            let bat100_img: Image<Bmp<BinaryColor>> = Image::new(&bat100, Point::new(bat_x, bat_y));
            let usbpwr = Bmp::from_slice(include_bytes!("./img/usb-power.bmp")).unwrap();
            let usbpwr_img: Image<Bmp<BinaryColor>> = Image::new(&usbpwr, Point::new(bat_x, bat_y));
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

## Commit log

2025-08-06 Add gerber file
2025-08-11 Fixed measurement for voltage
    [displayctl.rs, main.rs]
2025-08-11 Remove calibration reset function
    [main.rs]

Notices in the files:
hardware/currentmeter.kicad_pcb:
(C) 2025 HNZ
